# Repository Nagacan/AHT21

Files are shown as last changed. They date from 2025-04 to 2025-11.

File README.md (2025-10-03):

# AHT21
Tutorial to create a temperature and humidity sensor using AHT21 and Raspberry Pi Zero W. 
## Capabilties:
- Live temperature and humidity graph every 2 seconds
- Historical graph with the ability to view previous dates
- Downloadable data and sortable historical data table
- Automatic data logging starts as soon as the Raspberry Pi is powered on 
- Local web interface becomes available once the Pi is connected to Wi-Fi
- Smart disk monitoring: Automatically deletes old data when storage is low
- Timezone auto-configuration via systemd
- Fully autonomous: no user interaction needed after power-up

**Note: Names of Files, passwords, IDs, and Directories (location files are in) are important!**
## Quick Install (Terminal/SSH)
Input the Following into the Terminal (after you SSH into the Pi): 
1. git clone https://github.com/Nagacan/AHT21.git
2. cd AHT21/
3. chmod +x install.sh
4. ./install.sh

(Optional if you want to uninstall; skip step 1/2 below if already did above)
1. git clone https://github.com/Nagacan/AHT21.git
2. cd AHT21/
3. chmod +x uninstall.sh
4. ./uninstall.sh

## Resets/Debugging
If the webpage doesnt load ssh into the PI, or there is an error with backend
1. ssh into the PI
2. `cd AHT21/`
3. `source environment/bin/activate`
4. `sudo systemctl daemon-reload`
5. `sudo systemctl restart backend.service`
6. `sudo systemctl status backend.service`

 `journalctl -u backend.service -n 20 --no-pager` - is used for checking logs 
 
 ` journalctl -u backend.service -f `  - is used for live logs

 `systemctl is-active backend.service ` - check only if it’s running

` i2cdetect -y 1 ` - used to check addresses for I2c on bus 1

## Materials:
Raspberry Pi Zero WH (W= Wireless, H= Headers (already soldered on))

[RPi](https://www.amazon.com/Raspberry-Bluetooth-Compatible-Connector-headers/dp/B0CG99MR5W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)

AHT21 Sensor (Adafruit Humidity Temperature Sensors; brand matters -> code library used "adafruit_ahtx0")

[AHT21 Sensors](https://www.amazon.com/UMLIFE-Precision-Temperature-Measurement-Communication/dp/B0C6DZ8YZG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)

Breadboard and Jumper Wires 

(__**Male to Female / Female to Male**__ wires; need 4 wires to connect the sensors to the breadboard and RPi; any breadboard is fine)

[Breadboard/Wire Set](https://www.amazon.com/HUAREW-Breadboard-Jumper-Include-Points/dp/B09VKYLYN7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)

Micro-USB Cable and USB Power Supply (any is fine)

[Micro-USB Cable](https://www.amazon.com/Charging-Transfer-Android-Trustable-MYFON/dp/B098DW7485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)
 | [Power Supply with Micro-USB](https://www.amazon.com/Bawofu-Supply-Charger-Adapter-Universal/dp/B0BSF3TB8P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)

Micro SD-Card (I used 16 and 32gbs)

[Micro SD-Card](https://www.amazon.com/Center-Memory-Adapter-Mobile-Storage/dp/B08HD83TFJ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)

Micro SD-Card Reader/Adapter

[Adapter](https://www.amazon.com/Reader-Adapter-Camera-Memory-Wansurs/dp/B0B9QZ4W4Y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)

## Connections
[RPi Pinout](https://www.theengineeringprojects.com/2021/03/what-is-raspberry-pi-zero-pinout-specs-projects-datasheet.html)
<p align="center">
  
  
</p>

**_Use Male to Female Pins (Connect Male to Sensor/Breadboard, and Females to GPIO Pins on RPi)_**

1. VCC (or VIN) on the Sensor to 3.3V on the Pi
2. GND (Ground) on the Sensor to Ground on the Pi
3. SDA (Data) on the Sensor to GPIO2 (SDA1) on the Pi
4. SCL (Clock) on the sensor to GPIO3 (SCL1) on the Pi

# Detailed Guide

## Setting Up the Raspberry Pi (headless)
### 1. Flash Raspberry Pi OS
1. Use Raspberry Pi Imager to flash Raspberry Pi OS onto your SD card.
2. In the Configure OS imager settings:
   * Set your hostname (default: raspberrypi)
   * Set Username/Pass (e.g., admin/admin)
   * Configure Wireless LAN (Wifi/Hotspot SSID and Password)
   * Set country: US, timezone: America/Los_Angeles, keyboard: US
   * Enable SSH (Password Auth)
3. Click save and flash the SD card. This will erase all existing content

### 2. Additional Boot Setup
1. After flashing, open the `bootfs` partition on the SD card
2. Add the following files (or download/import from the one's I already provided in the folder: `RaspberryPi_Setup` for this Repository):
   * a blank file named `ssh`
   * a `wpa_supplicant.conf` file (or `.txt`, rename later if needed) with your specific Wi-Fi config
*If you're using the uploaded config file I provided be sure to edit the contents and change accordingly*

### 3. Boot and Connect
1. Insert the SD card into the Pi and power via micro USB
2. Wait ~5-10 mins. If it doesn't connect to Wi-Fi, unplug and retry/wait.
   * If still doesn't work may be issue with your Wi-Fi configuration
3. SSH into the Pi using CMD Terminal, Or Putty (3rd party app)
   * Default `ssh pi@raspberrypi.local`
   * Custom: `ssh <username>@<hostname>.local` or  `<username>@<IP_ADDRESS>`
4. Accept the SSH Key fingerprint and login with your password (It won't show that you're typing anything)
  
## Initial Configuration
1. Run these commands (one after another) into the terminal
```
sudo apt-get update
sudo raspi-config
```
* Change password (`System Options -> Password`)
* Enable I2C (`Interfacing Options -> I2C -> Enable`)
2. Install Dependencies:
```
sudo apt install -y build-essential git libi2c-dev i2c-tools
```
What These Do:
* build-essential: gcc, g++, make, and other dev tools
* git: Clone and manage repositories
* 2c-dev / i2c-tools: I²C support and tools like i2cdetect
3. Adjust the time to your region. LA as an example is below.
```
sudo timedatectl set-timezone America/Los_Angeles 
```
4. Reboot:
```
sudo reboot
```

### 4. Sensor Setup (AHT21)
1. Create Virtual Environment
```
mkdir ~/AHT21
cd ~/AHT21
python3 -m venv environment
source environment/bin/activate
```
*For the rest of the guide, you must be in this directory and environment*
2. Install Sensor Library
```
pip3 install adafruit-circuitpython-ahtx0
```
*Note: Ignore warnings like "retrying after connection broken." Just wait.*

### 5. Install Flask and NGINX
1. Install flask
```
pip3 install flask flask-cors
```
2. Install NGINX by following [NGINX](https://nginx.org/en/linux_packages.html#Debian) Debian Instructions or use commands below:
```
sudo apt install curl gnupg2 ca-certificates lsb-release debian-archive-keyring

curl https://nginx.org/keys/nginx_signing.key | gpg --dearmor \
  | sudo tee /usr/share/keyrings/nginx-archive-keyring.gpg >/dev/null

gpg --dry-run --quiet --no-keyring --import --import-options import-show \
  /usr/share/keyrings/nginx-archive-keyring.gpg

echo "deb [signed-by=/usr/share/keyrings/nginx-archive-keyring.gpg] \
http://nginx.org/packages/debian `lsb_release -cs` nginx" \
  | sudo tee /etc/apt/sources.list.d/nginx.list

# Optionally add mainline repo
echo "deb [signed-by=/usr/share/keyrings/nginx-archive-keyring.gpg] \
http://nginx.org/packages/mainline/debian `lsb_release -cs` nginx" \
  | sudo tee /etc/apt/sources.list.d/nginx.list

echo -e "Package: *\nPin: origin nginx.org\nPin: release o=nginx\nPin-Priority: 900\n" \
  | sudo tee /etc/apt/preferences.d/99nginx

# Install NGINX
sudo apt update
sudo apt install nginx
```

### 5. Backend and Frontend Configuration
1. Setup Flask App and SystemD Service
2. Go to the your project folder and create/import (Import the Backend Folder in my repository `Backend_Code`) Flask Backend
```
cd ~/AHT21
source environment/bin/activate
sudo nano backend.py
```
3. Install SQLite
```
sudo apt install sqlite3
```
4. Setup Systemd Service file (or import from `SystemD`)
```
sudo nano /etc/systemd/system/backend.service
```
* Remember to replace with your Username
5. Reload and enable the service
```
sudo systemctl daemon-reload
sudo systemctl enable backend.service
sudo systemctl start backend.service
sudo systemctl status backend.service
```

### 6. Web Frontend Pages
1. Create/Import these HTML Files `Frontend_Code`
```
sudo nano /var/www/html/index.html
sudo nano /var/www/html/history.html
```
2. Configure NGINX config (or import from `NGINX_Setup`) and restart 
```
sudo nano /etc/nginx/sites-available/default
sudo systemctl restart nginx
```

### 7. Access your site
1. Find your Pi's IP and Visit `(http://<YOUR_PI_IP>)`:
```
hostname -I
```
**Always activate your virtual environment before running Python code:**
*  ` source environment/bin/activate `
*  use `deactivate` to exit the environment

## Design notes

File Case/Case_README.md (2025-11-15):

Here are the files in case you want to replicate the case that I designed using CAD software. Modeled in Fusion.

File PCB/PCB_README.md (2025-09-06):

Here is if you want to replicate the PCB for the sensor. I used EasyEDA (Standard Edition) to create the PCB and schematic.

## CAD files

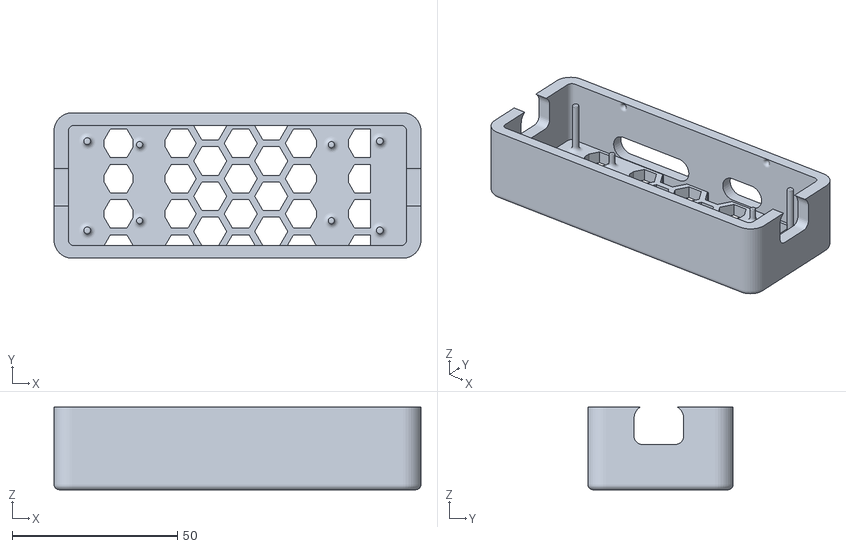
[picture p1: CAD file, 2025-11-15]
Case/Humidity and Temperature Case_Configuration 1_Bottom.stl
111.0 x 44.0 x 25.0

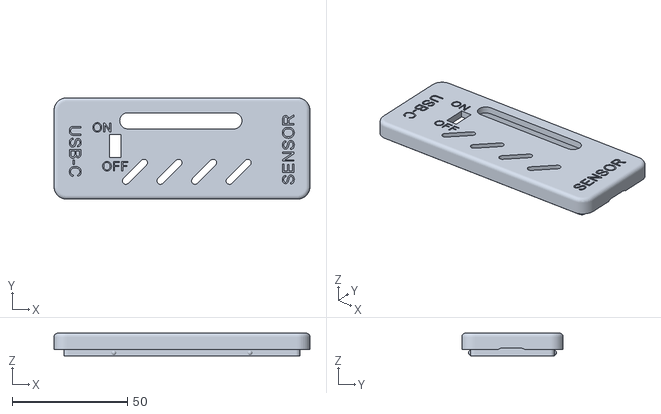
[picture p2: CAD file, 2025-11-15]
Case/Humidity and Temperature Case_Configuration 1_Top.stl
111.0 x 44.0 x 9.85

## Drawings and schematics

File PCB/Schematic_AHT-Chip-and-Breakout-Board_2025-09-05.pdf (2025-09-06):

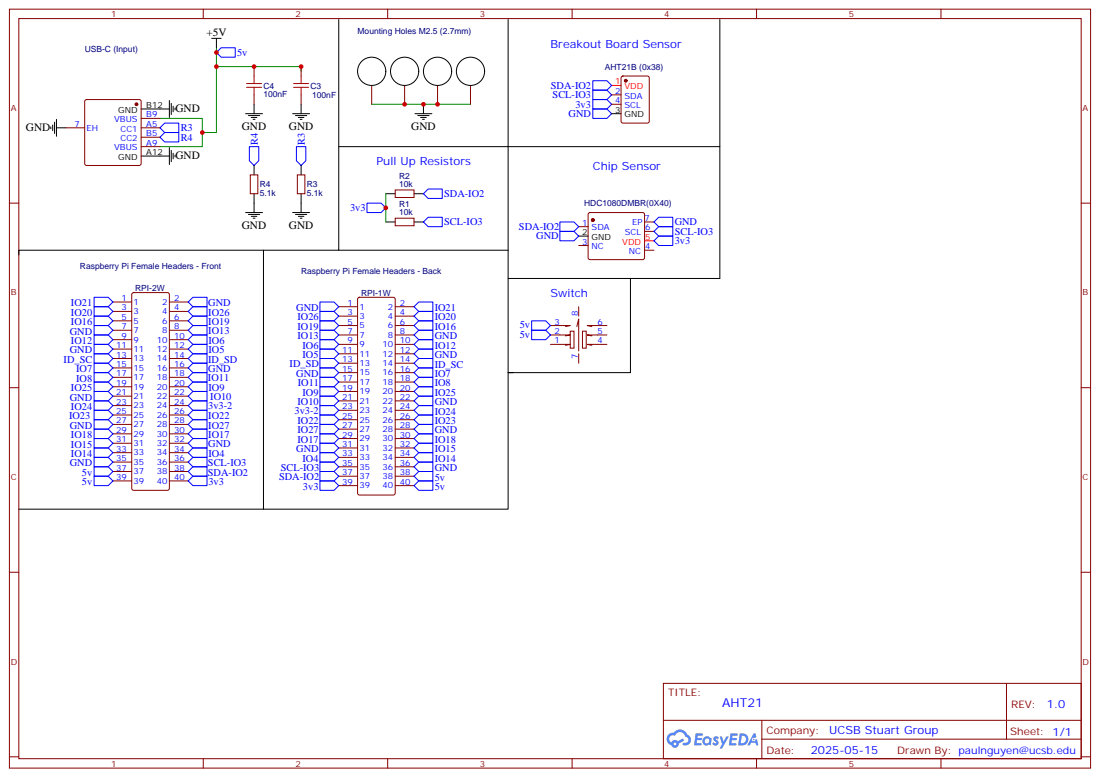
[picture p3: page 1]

Raspberry Pi Female Headers - Front

Raspberry Pi Female Headers - Back

Company: UCSB Stuart Group

Drawn By: paulnguyen@ucsb.edu

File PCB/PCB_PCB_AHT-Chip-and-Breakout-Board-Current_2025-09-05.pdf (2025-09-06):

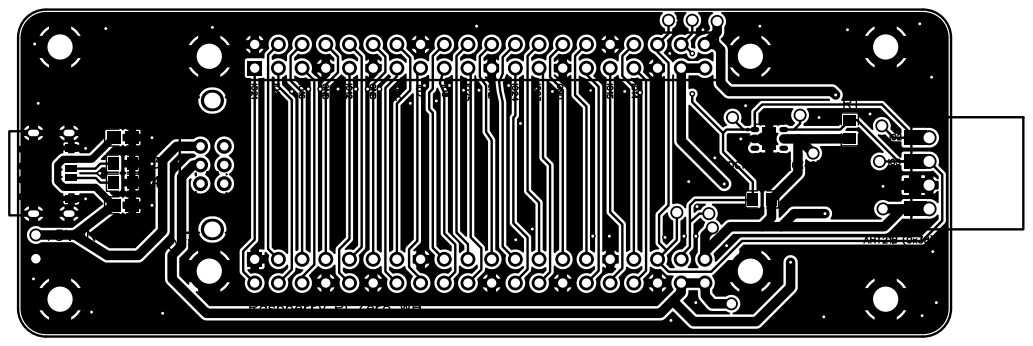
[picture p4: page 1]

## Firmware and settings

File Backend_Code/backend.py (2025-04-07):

# Copy and paste this into your backend file, or just import the file
import os
import time
import threading
import sqlite3
import board
import adafruit_ahtx0
from datetime import datetime
from flask import Flask, jsonify
from flask_cors import CORS

# Flask App and setup
app = Flask(__name__)
CORS(app)

# Get the directory where backend.py is located (dynamic path)
BASE_DIR = os.path.dirname(os.path.abspath(__file__))
db_path = os.path.join(BASE_DIR, "sensor_data.db")  # Dynamic database path

# Sensor Setup
i2c = board.I2C()
sensor = adafruit_ahtx0.AHTx0(i2c)

# Storage Threshold (in MB)
THRESHOLD_MB = 500
db_lock = threading.Lock()  # Only one thread can interact with the database at a time

# Creates the table for sqlite 
def initialize_database():
    """Ensure the sensor_data table exists."""
    try: # Try blocks : if get error go instantly to exception
        conn = sqlite3.connect(db_path) # Opens a connection to your SQLite database.
        c = conn.cursor() # Prepares a cursor to execute SQL commands and creates table ->
        c.execute("""
            CREATE TABLE IF NOT EXISTS sensor_data (
                timestamp TEXT,
                temperature REAL,
                humidity REAL
            );
        """)
        conn.commit() # Commits changes
        conn.close() # Closes the connection
        print("Database initialized successfully.")
    except Exception as e: # Instead of crashing entire program prints this
        print(f"Error initializing database: {e}")

# Call this function at startup so that it creates the table
initialize_database()

#allows multiple readers with 1 writer
def enable_wal_mode():
    """Enable Write-Ahead Logging (WAL) mode to allow multiple readers while writing."""
    try:
        with db_lock:
            conn = sqlite3.connect(db_path, check_same_thread=False) # Allows this connection to be used in threads other than the one that created it 
            conn.execute("PRAGMA journal_mode=WAL;") # PRAGMA command to switch the journaling mode to WAL
            conn.execute("PRAGMA synchronous=NORMAL;") # Controls how carefully SQLite waits for data to be fully written to disk during a COMMIT
            conn.close() # Closes the database connection 
            print("WAL mode enabled for SQLite.")
    except Exception as e:
        print(f"Error enabling WAL mode: {e}")

enable_wal_mode()  # Run this once at startup

# Checks how much free storage is available and returns in mgbs
def get_free_space_mb():
    """Check available storage on the SD card in MB."""
    statvfs = os.statvfs("/") # Gets filesystem statistics for the given path in root directory
    free_space = (statvfs.f_bavail * statvfs.f_frsize) / (1024 * 1024)  # Calculates total space then converts to MB (total space /(1024 * 1024))
    return free_space

# Deletes oldest day worth of data
def delete_oldest_data():
    """Delete the oldest day's data from the database if storage is low."""
    try:
        conn = sqlite3.connect(db_path)
        cursor = conn.cursor()
# 79-80 Checks oldest date; ignores the time part and just compares by day
        cursor.execute("SELECT MIN(DATE(timestamp)) FROM sensor_data")
        oldest_date = cursor.fetchone()[0]
# If a date exists (meaning the table has data), go ahead and delete. If not prints nothing to delete. 
        if oldest_date:
            print(f"Deleting data from {oldest_date} to free up space...")
            cursor.execute("DELETE FROM sensor_data WHERE DATE(timestamp) = ?", (oldest_date,))
            conn.commit()
            print(f"Data from {oldest_date} deleted successfully.")
        else:
            print("No data found to delete.")
# Closes the connection
        conn.close()
    except Exception as e:
        print(f"Error deleting old data: {e}")

# Checks every 10 minutes to see if storage is ok
def monitor_storage():
    """Continuously check storage and delete old data when needed."""
    while True: # Runs continuously
        free_space = get_free_space_mb() # Gets the current free space in MB using the helper function.
        print(f"Available storage: {free_space:.2f} MB") # Prints it with 2 decimal precision so you can see storage dropping or increasing over time.
# If free space is below a threshold (e.g. THRESHOLD_MB = 100), it deletes the oldest day’s data. If there's enough space, it just prints a status update.
        if free_space < THRESHOLD_MB: # Checks free space with threshold we set earlier
            print("Low storage detected! Deleting oldest data...")
            delete_oldest_data() # Runs the function we made above to delete oldest data
        else:
            print("Storage is sufficient, no need to delete data.")
# Sets a 10 minute delay before the function reruns
        time.sleep(600)  # Check every 10 minutes

# Run storage cleanup in a background thread
storage_thread = threading.Thread(target=monitor_storage, daemon=True) # Tells the thread to run the monitor function we made above and run it as daemon thread (automatically exit when the main program exits)
storage_thread.start() # Starts the thread

#logs the live sensor data
def log_data():
    """Log sensor data into the database."""
    try:
        conn = sqlite3.connect(db_path)
        c = conn.cursor()

        current_time = datetime.now().strftime("%Y-%m-%d %H:%M:%S") # Takes current time and formats it into a human-readable string
        temperature = sensor.temperature  # Pull data from your sensor object 
        humidity = sensor.relative_humidity # Pull data from your sensor object 
# SQL command inserts the data using ? placeholders for safety (avoids SQL injection).
        c.execute('INSERT INTO sensor_data (timestamp, temperature, humidity) VALUES (?, ?, ?)',
                  (current_time, temperature, humidity))
        conn.commit() # Commits the change
        conn.close() # Closes connection
    except Exception as e:
        print(f"Error logging data: {e}")
# This will keep logging data to your database at 2-second intervals — indefinitely.
def periodic_logging():
    """Continuously log data every 2 seconds."""
    while True: # Forever Loop 
        start_time = time.time() # Captures the start time before logging.
        log_data() # Calls log_data() (which talks to the sensor + DataBase).
        elapsed_time = time.time() - start_time # Calculates how long that took.
        time_to_wait = max(0, 2 - elapsed_time) # Subtracts elapsed_time from 2 seconds to determine how long to sleep. Max makes sure no negative
        time.sleep(time_to_wait)

# Start the data logging in a separate thread, runs the logging function, daemon thread, and starts
threading.Thread(target=periodic_logging, daemon=True).start()

@app.route('/data', methods=['GET']) # Flask route that listens at /data for GET requests.
def get_data():
    """API endpoint to get live sensor data."""
    try:
        current_time = datetime.now().strftime("%Y-%m-%d %H:%M:%S") # Current system time in a readable format. Below gets data to 2 decimal points
        data = {
            "time": current_time,
            "temperature": round(sensor.temperature, 2),
            "humidity": round(sensor.relative_humidity, 2)
        }
        return jsonify(data) # Returns JSON response
    except Exception as e: # Returns a 500 Internal Server Error if something breaks. No crashes
        return jsonify({"error": f"Failed to fetch live data: {e}"}), 500

@app.route('/history', methods=['GET']) # Sets up a Flask GET endpoint at /history.
def get_history():
    """API endpoint to get historical sensor data sorted by day."""
    try:
        conn = sqlite3.connect(db_path)
        c = conn.cursor() # Below use GROUP_CONCAT to bundle all times, temps, and humidity values as comma-separated strings per day. Return them sorted from newest to oldest.
        c.execute("""
            SELECT DATE(timestamp) AS date,
                   GROUP_CONCAT(TIME(timestamp)) AS times,
                   GROUP_CONCAT(temperature) AS temperatures,
                   GROUP_CONCAT(humidity) AS humidities
            FROM sensor_data
            GROUP BY date
            ORDER BY date DESC
        """)
        rows = c.fetchall()
        conn.close()
# Splits the comma-separated values into actual Python lists. Converts temperature and humidity strings to floats. Creates a list of dicts
        grouped_data = [
            {
                "date": row[0],
                "times": row[1].split(","),
                "temperatures": [float(t) for t in row[2].split(",")],
                "humidities": [float(h) for h in row[3].split(",")]
            }
            for row in rows
        ]
        return jsonify(grouped_data)
    except Exception as e:
        return jsonify({"error": f"Failed to fetch historical data: {e}"}), 500

if __name__ == '__main__': # This checks whether the script is being run directly 
    try:
        app.run(host='0.0.0.0', port=5000) # Makes the server accessible from any IP on the local network (important for Raspberry Pi setups). Uses default Flask Port
    except Exception as e:
        print(f"Error starting the server: {e}")

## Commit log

2025-02-21 Create RaspberryPi_Setup
2025-04-01 Update uninstall.sh
    added cd ~ in remove project directory, gave a repeated error that can happen when the current working directory (pwd) is deleted while you're still inside it
2025-09-06 Update and rename dfs to PCB_README.md
